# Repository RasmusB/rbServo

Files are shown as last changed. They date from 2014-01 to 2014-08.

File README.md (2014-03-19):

# rbServo Readme

### What is it?
All the hardware and software that is needed to build a CAN-BUS servo controller. It is meant to be used for RC servos.

### What does it contain?

- `3D` - hardware components

- `HW` - all the hardware design files are in this folder

- `SW` - The software for the servo.
 - `rbServoFirmware` - Servo controller firmware

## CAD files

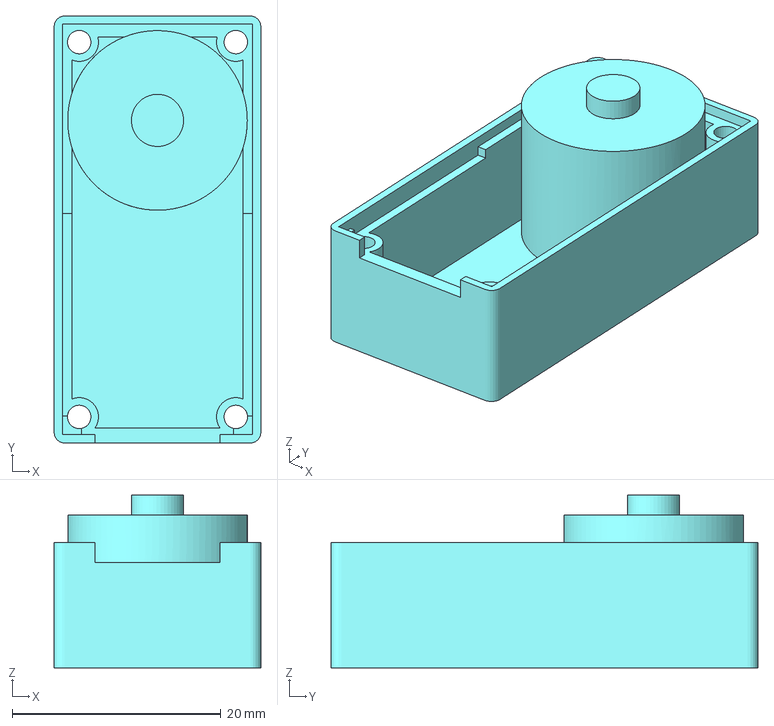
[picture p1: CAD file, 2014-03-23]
3D/rbServo-Assy.fcstd
19.8 x 40.9 x 16.5 mm

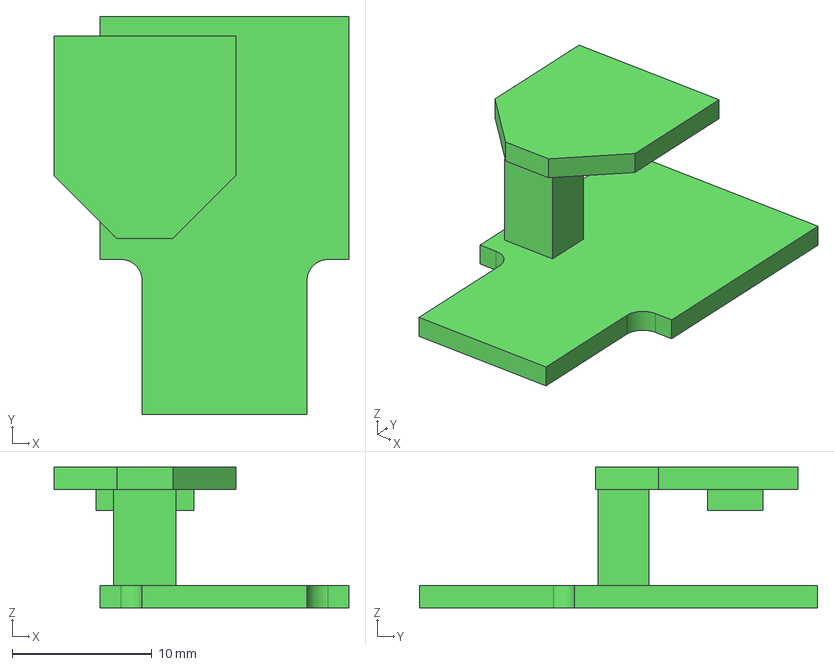
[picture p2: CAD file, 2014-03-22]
3D/rbServo-PCB.fcstd
21.1 x 28.5 x 10.1 mm

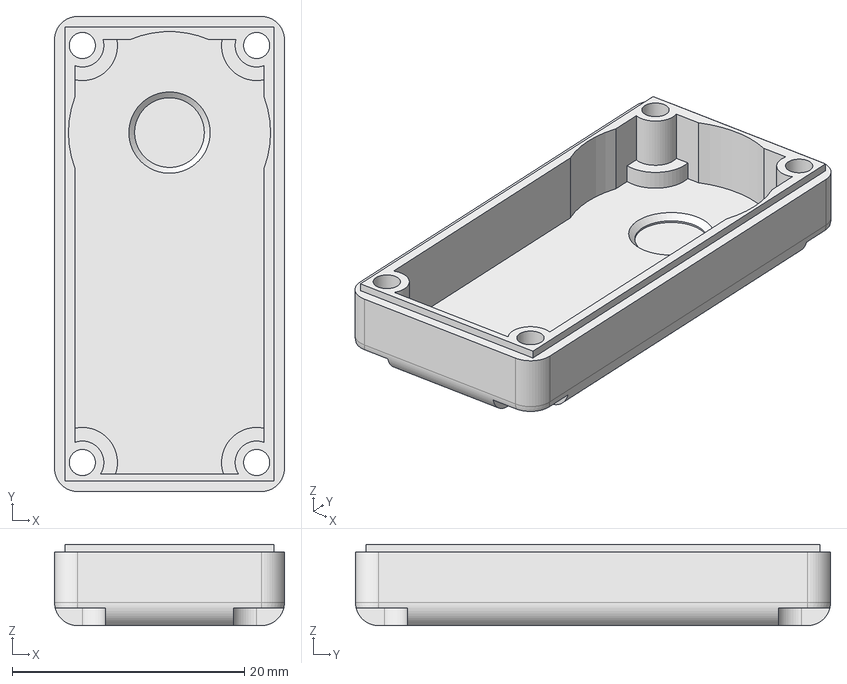
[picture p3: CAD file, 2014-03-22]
3D/MG995 Servo Lid.fcstd
19.8 x 40.9 x 7.00 mm

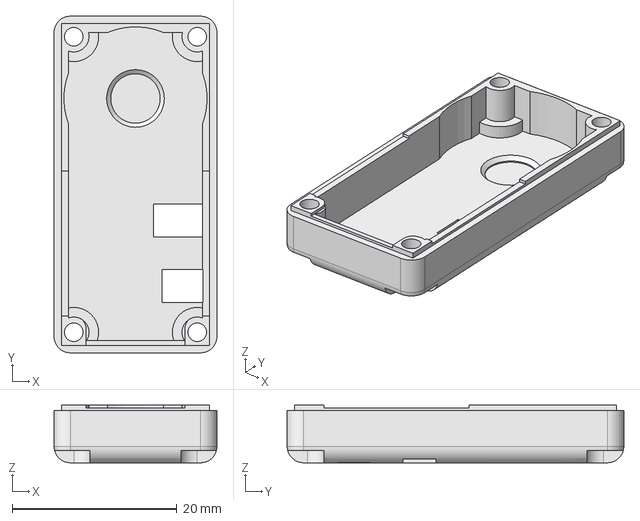
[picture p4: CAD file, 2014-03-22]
3D/rbServo-Lid.fcstd
19.8 x 40.9 x 7.00 mm

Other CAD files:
3D/rbServo-Body.fcstd
3D/MG995 Servo Body.fcstd

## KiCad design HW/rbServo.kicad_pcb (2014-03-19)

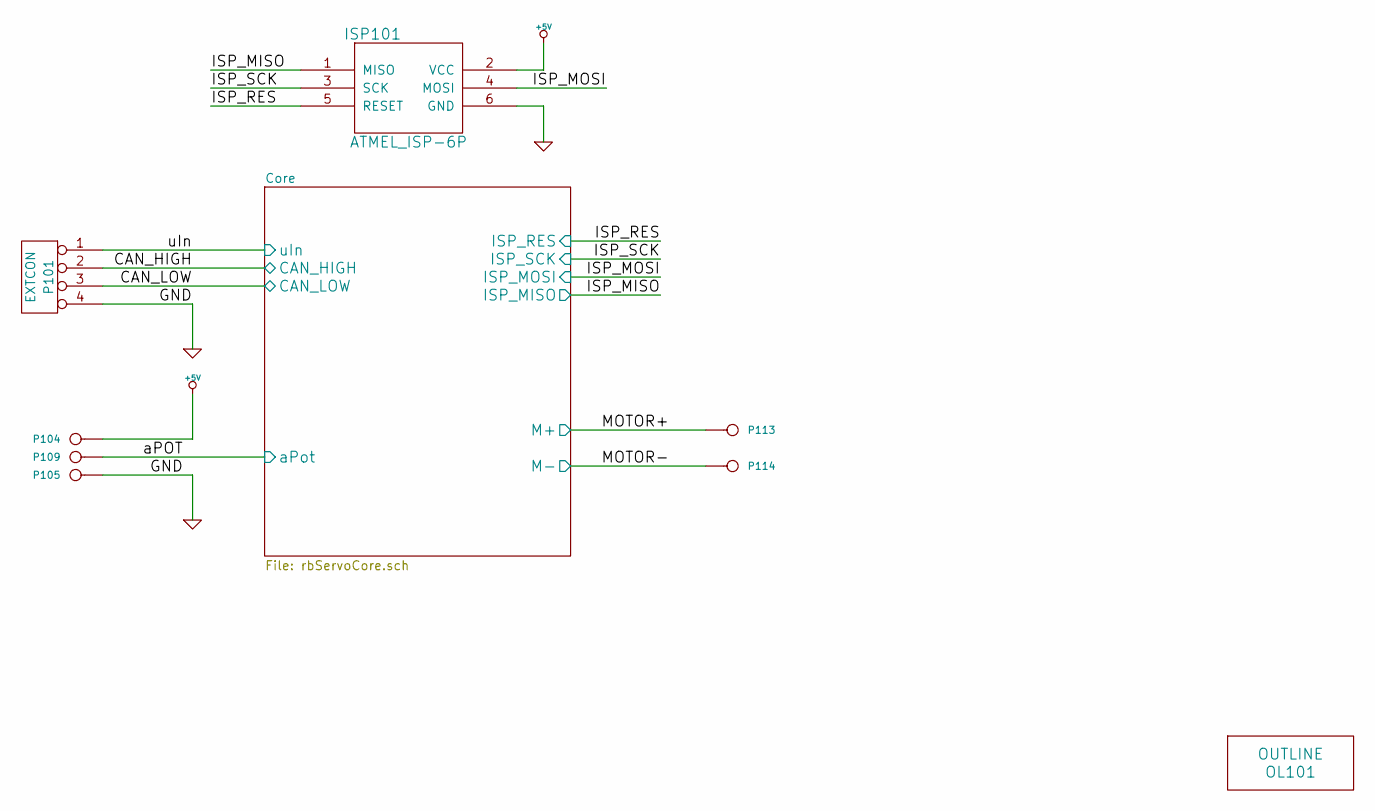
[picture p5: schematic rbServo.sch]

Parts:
ISP101: ATMEL_ISP-6P
OL101: OUTLINE
P101: EXTCON
P104: 5V
P105: GND
P109: Pot
P113: M+
P114: M-

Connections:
+5V: ISP101.2 (VCC), P104.1; also elsewhere on the board
/Core/CAN_HIGH: P101.2; also elsewhere on the board
/Core/CAN_LOW: P101.3; also elsewhere on the board
/Core/ISP_MISO: ISP101.1 (MISO); also elsewhere on the board
/Core/ISP_MOSI: ISP101.4 (MOSI); also elsewhere on the board
/Core/ISP_RES: ISP101.5 (RESET); also elsewhere on the board
/Core/ISP_SCK: ISP101.3 (SCK); also elsewhere on the board
/Core/M+: P113.1; also elsewhere on the board
/Core/M-: P114.1; also elsewhere on the board
/Core/aPot: P109.1; also elsewhere on the board
/Core/uIn: P101.1; also elsewhere on the board
GND: ISP101.6 (GND), P101.4, P105.1; also elsewhere on the board

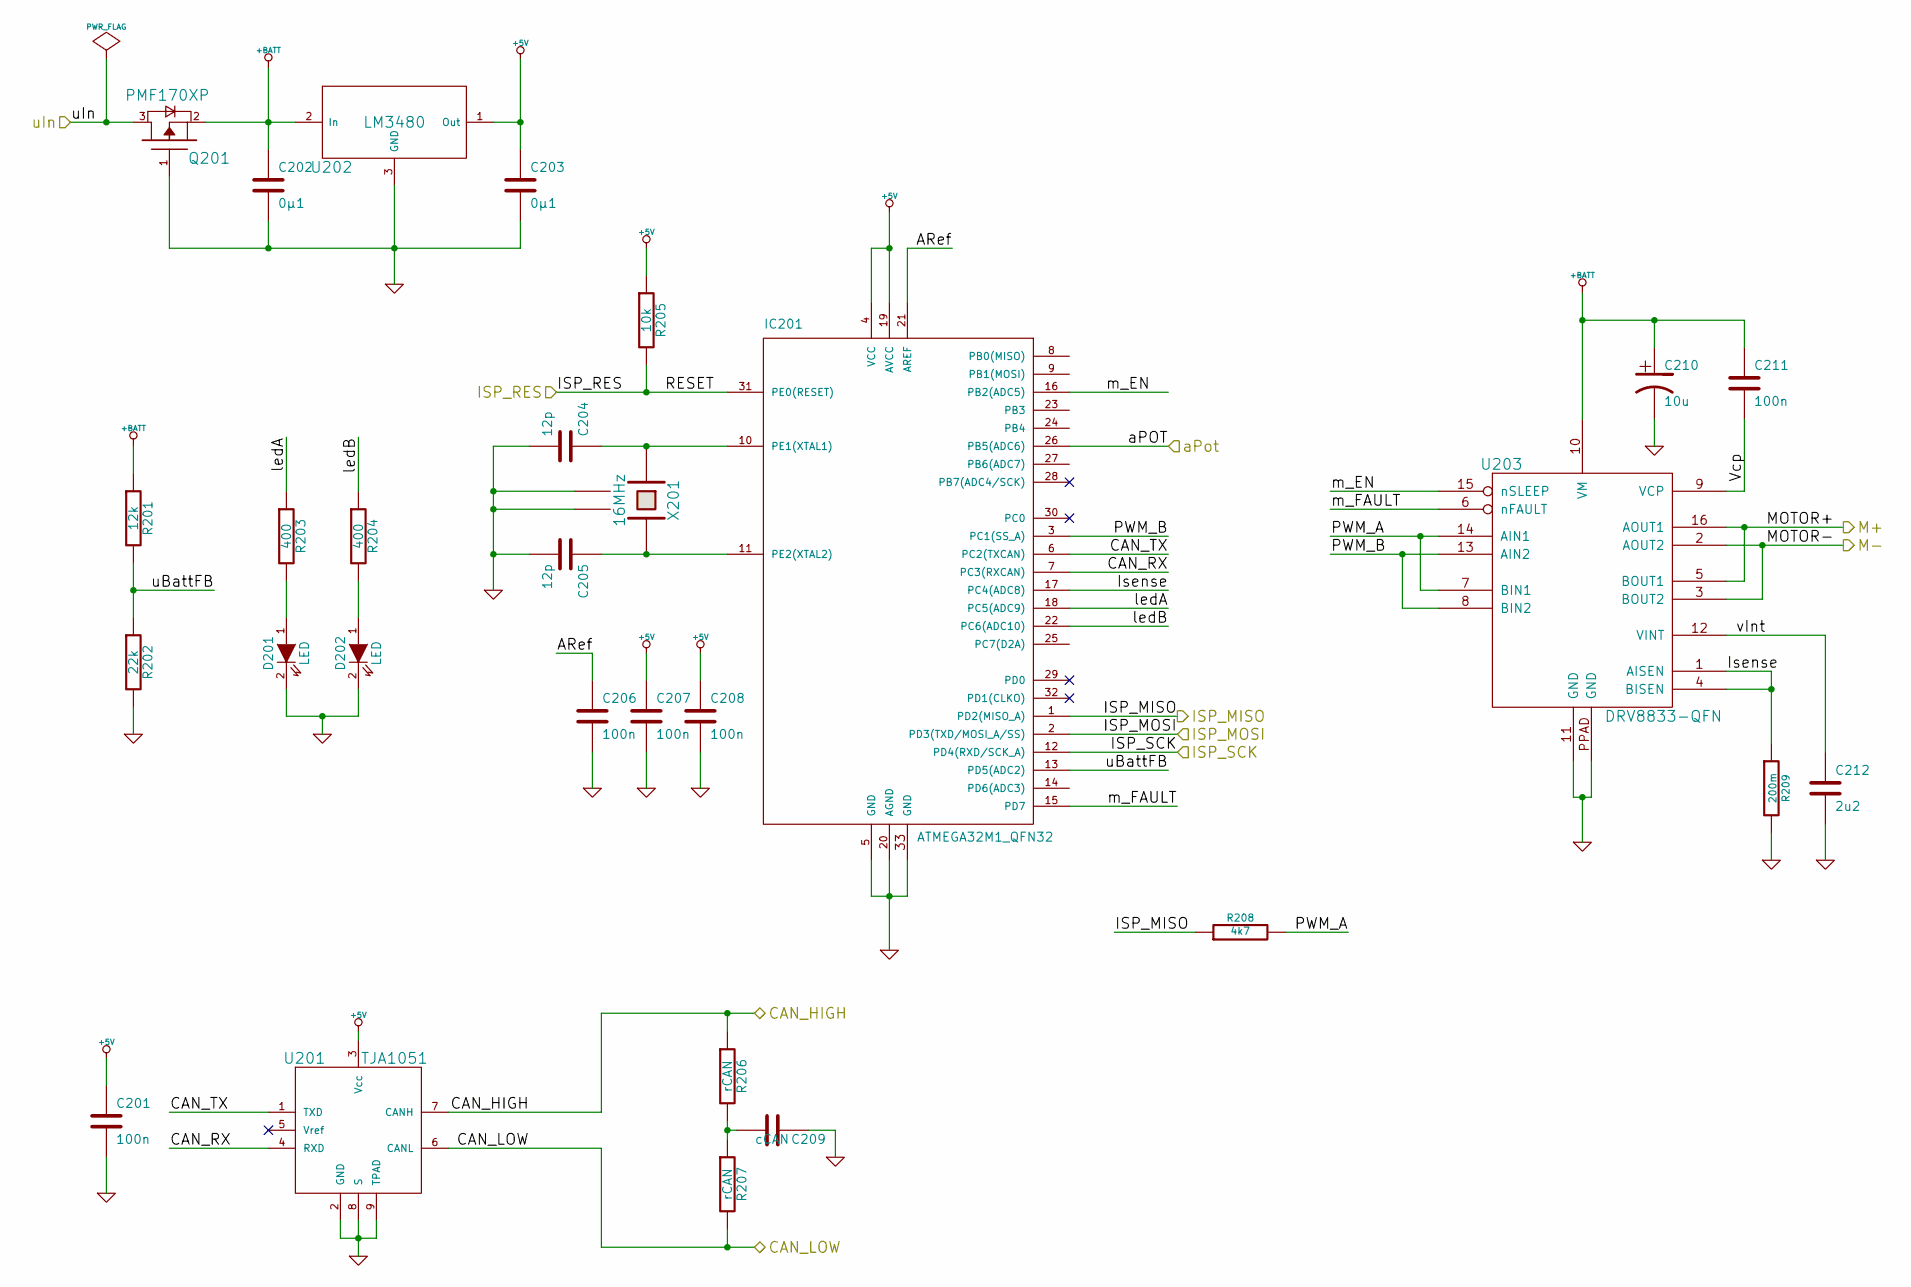
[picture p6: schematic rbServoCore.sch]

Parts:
C201, C206, C207, C208, C211: 100n
C202, C203: 0µ1
C204, C205: 12p
C209: cCAN
C210: 10u
C212: 2u2
D201, D202: LED
IC201: ATMEGA32M1_QFN32; MLF32
Q201: PMF170XP
R201: 12k
R202: 22k
R203, R204: 400
R205: 10k
R206, R207: rCAN
R208: 4k7
R209: 200m
U201: TJA1051
U202: LM3480; Mouser 926-LM3480IM35.0NOPB
U203: DRV8833-QFN
X201: 16MHz

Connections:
+5V: C201.1, C203.1, C207.1, C208.1, IC201.4 (VCC), IC201.19 (AVCC), R205.1, U201.3 (Vcc), U202.1 (Out); also elsewhere on the board
+BATT: C202.1, C210.1, C211.1, Q201.2 (S), R201.1, U202.2 (In), U203.10 (VM)
/Core/ARef: C206.1, IC201.21 (AREF)
/Core/CAN_HIGH: R206.1, U201.7 (CANH); also elsewhere on the board
/Core/CAN_LOW: R207.2, U201.6 (CANL); also elsewhere on the board
/Core/CAN_RX: IC201.7 (PC3(RXCAN)), U201.4 (RXD)
/Core/CAN_TX: IC201.6 (PC2(TXCAN)), U201.1 (TXD)
/Core/ISP_MISO: IC201.1 (PD2(MISO_A)), R208.1; also elsewhere on the board
/Core/ISP_MOSI: IC201.2 (PD3(TXD/MOSI_A/SS)); also elsewhere on the board
/Core/ISP_RES: IC201.31 (PE0(RESET)), R205.2; also elsewhere on the board
/Core/ISP_SCK: IC201.12 (PD4(RXD/SCK_A)); also elsewhere on the board
/Core/Isense: IC201.17 (PC4(ADC8)), R209.1, U203.1 (AISEN), U203.4 (BISEN)
/Core/M+: U203.5 (BOUT1), U203.16 (AOUT1); also elsewhere on the board
/Core/M-: U203.2 (AOUT2), U203.3 (BOUT2); also elsewhere on the board
/Core/PWM_A: R208.2, U203.7 (BIN1), U203.14 (AIN1)
/Core/PWM_B: IC201.3 (PC1(SS_A)), U203.8 (BIN2), U203.13 (AIN2)
/Core/Vcp: C211.2, U203.9 (VCP)
/Core/aPot: IC201.26 (PB5(ADC6)); also elsewhere on the board
/Core/ledA: IC201.18 (PC5(ADC9)), R203.1
/Core/ledB: IC201.22 (PC6(ADC10)), R204.1
/Core/m_EN: IC201.16 (PB2(ADC5)), U203.15 (nSLEEP)
/Core/m_FAULT: IC201.15 (PD7), U203.6 (nFAULT)
/Core/uBattFB: IC201.13 (PD5(ADC2)), R201.2, R202.1
/Core/uIn: Q201.3 (D); also elsewhere on the board
/Core/vInt: C212.1, U203.12 (VINT)
GND: C201.2, C202.2, C203.2, C204.2, C205.2, C206.2, C207.2, C208.2, C209.1, C210.2, C212.2, D201.2 (K), D202.2 (K), IC201.5 (GND), IC201.20 (AGND), IC201.33 (GND), Q201.1 (G), R202.2, R209.2, U201.2 (GND), U201.8 (S), U201.9 (TPAD), U202.3 (GND), U203.11 (GND), U203.PPAD (GND), X201.2 (GND), X201.4 (GND); also elsewhere on the board
unnamed: C204.1, IC201.10 (PE1(XTAL1)), X201.1
unnamed: C205.1, IC201.11 (PE2(XTAL2)), X201.3
unnamed: C209.2, R206.2, R207.1
unnamed: D201.1 (A), R203.2
unnamed: D202.1 (A), R204.2

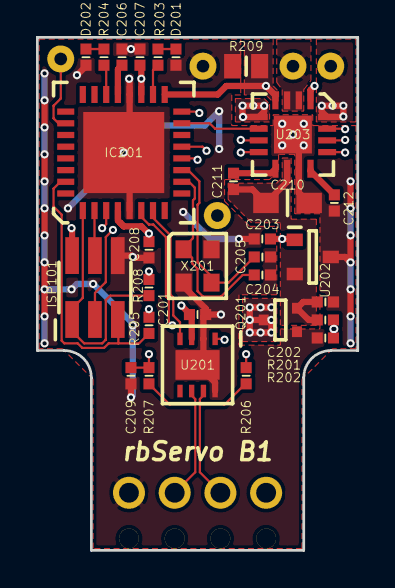
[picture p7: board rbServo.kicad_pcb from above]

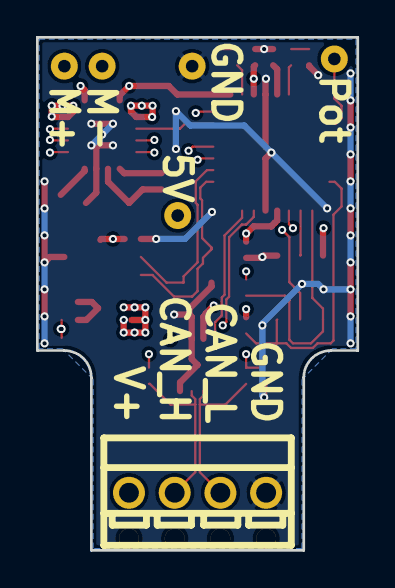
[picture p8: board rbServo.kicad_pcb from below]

Board: 4 copper layers, 17.8 x 28.5 mm, 37 parts (6 on the bottom side), 31 nets.

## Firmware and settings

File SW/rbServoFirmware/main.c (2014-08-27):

/*
The MIT License (MIT)

Copyright (c) 2014 Rasmus Backman

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
THE SOFTWARE IS PROVIDED "AS IS", WITHOUT WARRANTY OF ANY KIND, EXPRESS OR
IMPLIED, INCLUDING BUT NOT LIMITED TO THE WARRANTIES OF MERCHANTABILITY,
FITNESS FOR A PARTICULAR PURPOSE AND NONINFRINGEMENT. IN NO EVENT SHALL THE
AUTHORS OR COPYRIGHT HOLDERS BE LIABLE FOR ANY CLAIM, DAMAGES OR OTHER
LIABILITY, WHETHER IN AN ACTION OF CONTRACT, TORT OR OTHERWISE, ARISING FROM,
OUT OF OR IN CONNECTION WITH THE SOFTWARE OR THE USE OR OTHER DEALINGS IN THE
SOFTWARE.
*/

#include <avr/io.h>
#include <avr/interrupt.h>
#include <stdlib.h>
#include <stdbool.h>

#include "adc.h"
#include "board.h"
#include "canbus.h"
#include "eepromConfig.h"
#include "motor.h"
//#include "pid.h"
#include "sensors.h"
#include "timer.h"

#define MOTOR_SPEED 0x1EFF

void init(void) __attribute__((constructor));

extern uint16_t sensorPotGetRaw();

uint8_t mirrorMCUSR __attribute__ ((section (".noinit")));

int main () {

	uint16_t i;

	mirrorMCUSR = MCUSR;

	// TODO: Check for new CAN data. Update behavior accordingly.

	// TODO: Check if enough time has elapsed. If so, update PID.
	// TODO: Update PWM output according to PID output

	// TODO: Update remote CAN frame data
		/*	disable "data valid" flag
		 *	write new data to buffer
		 *	set "data valid" flag
		 */

	grnLEDpwm( 0xFF );

//	motorSetSpeed ( MOTOR_SPEED );


	while (1) {

		int16_t tempPot = sensorPotGetValue();

		if (run10HzLoop) {
			run10HzLoop = 0;

			redLEDon();

//			if ( tempPot > 150 ) {
//				motorSetSpeed ( -MOTOR_SPEED );
//			} else if ( tempPot < -150 ) {
//				motorSetSpeed ( MOTOR_SPEED );
//			}

			canbusTxBuffer[1] = (int8_t) (tempPot >> 8);
			canbusTxBuffer[0] = (uint8_t) (tempPot & 0xFF);

			canbusTXsetup(010, 2, 1);

			redLEDoff();

		}





//		canbusRXsetup(0);
//
//		// Busy-Wait for a CAN message
//		while (CANSTMOB == 0);
//		CANSTMOB = 0x00;
//
//		rxID = (CANIDT1 << 3) + (CANIDT2 >> 5);
//		rxDLC = CANCDMOB & 0x0F;
//
//		for (i=0; i < rxDLC; i++) {
//			canbusRxDataBuffer[i] = CANMSG;
//		}
//
//		if (rxID == 0x123 && rxDLC == 2) {
//			pwmSetDutyCycle((canbusRxDataBuffer[0] << 8) + canbusRxDataBuffer[1]);
//		}

		//canbusTXsetup(rxID, rxDLC, 0); 	// This just echos the last received message

	}



	return 0;
}

void init() {
	// Read all node configuration data
	eepromReadConfiguration();

	// Initialize board IO
	boardInit();

	// Initialize AD converter
	adcInit();

	// Initialize PWM generation
	motorInit();

	// Initialize timer-based interrupts
	timerInit();

	// Initialize CAN bus
	canbusInit();

	// TODO: Initialize PID with EEPROM values
	// TODO: PID setpoint = current position

	// Enable Global Interrupts
	sei();
}

ISR(BADISR_vect)
{
    // This should not ever happen!
	// If this function executes, an unhandled interrupt occured.

	while (1) {
		redLEDon();
		grnLEDon();
	}
}

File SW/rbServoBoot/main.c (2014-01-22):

/*
 * main.c
 *
 *  Created on: Jan 22, 2014
 *      Author: rasmus
 */


// TODO: Create timer with mS resolution for PID loop

#include <avr/io.h>

#include "board.h"
#include "canbus.h"
#include "eepromConfig.h"

void init(void) __attribute__((constructor));

int main () {

	uint8_t i;
	uint8_t j;
	uint16_t rxID;
	uint8_t rxDLC;
	// TODO: Check for new CAN data. Update behavior accordingly.

	// TODO: Check if enough time has elapsed. If so, update PID.
	// TODO: Update PWM output according to PID output

	// TODO: Update remote CAN frame data
		/*	disable "data valid" flag
		 *	write new data to buffer
		 *	set "data valid" flag
		 */

	//redLEDpwm(0);
	while (1) {

		canbusRXsetup(0);

		// Busy-Wait for a CAN message
		while (CANSTMOB == 0);
		CANSTMOB = 0x00;

		rxID = (CANIDT1 << 3) + (CANIDT2 >> 5);
		rxDLC = CANCDMOB & 0x0F;

		//redLEDpwm(CANIDT1);

		for (i=0; i < rxDLC; i++) {
			canbusDataBuffer[i] = CANMSG;
		}

		// Send message
		canbusTXsetup(rxID, rxDLC, 0);
	}



	return 0;
}

void init() {
	boardInit();
	//eepromReadConfiguration();
	//adcInit();

	canbusInit();

	// TODO: Initialize PID with EEPROM values
		// TODO: PID setpoint = current position
	//redLEDoff();

	// First boot since reflash via bootloader
	/*
	if (BootStayIn) {
		BootStayIn = 0;
		eepromWriteConfiguration();
	}
	*/
	// Enable Global Interrupts
	SREG |= _BV(SREG_I);

	// TODO: Send CANBUS "Application Ready"
	// TODO: Wait for CANBUS "OK" response

}

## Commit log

2014-01-22 Initial commit, nothing useful yet
    [rbServoCore.sch, rbServoFinal.kicad_pcb, rbServoFinal.sch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]
2014-03-11 Work on all fronts. The software is taking shape now.
    [rbServoCore.sch, rbServoProto.kicad_pcb, rbServoProto.sch]
2014-03-12 .gitignore updated to ignore all KiCAD temporary "BAK" files
2014-03-12 Remove unneeded PWM for now
2014-03-12 Cleanup in the HW directory. - The "proto", "final" and "common" directories are joined to one single design, based on the latest prototype design. - Readme.md updated to reflect this change
    [rbServo.kicad_pcb, rbServo.sch, rbServoCore.sch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]
2014-03-13 Added simple software-based PWM for on board LED
2014-03-18 Trying new layout
    [rbServo.kicad_pcb, rbServo.sch]
2014-03-18 Started work on new servo lid for Tower Pro MG995 servo
    [Servo Lid.fcstd]
2014-03-19 -Swapped CAN_H and CAN_L -Changed a few labels - All new layout that should fit i a servo
    [rbServo.kicad_pcb, rbServo.sch, rbServoCore.sch]
2014-03-22 New version of the servo lid. A debugger port hole needs to be added for a debugger compatible version.
    [Servo Lid.fcstd]
2014-03-22 Work in progress on mechanical fit
    [MG995 Servo Body.fcstd, Servo Lid.fcstd, rbServo-RevB1-Assy.fcstd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]
2014-03-22 Servo lid model renamed for clarity
    [MG995 Servo Lid.fcstd, Servo Lid.fcstd]
2014-03-22 Model structure tweaks
    [MG995 Servo Body.fcstd, rbServo-RevB1-Assy.fcstd, rbServo-RevB1-PCB.fcstd]
2014-03-22 Another revision of the servo body to document the modifications needed to fit the B1 PCB.
    [rbServo-RevB1-Body.fcstd]
2014-03-23 Reshuffled file names again.
    No use having the filenames contain the version name when
    I'm using a version control system... doh!
    [rbServo-Assy.fcstd, rbServo-Body.fcstd, rbServo-Lid.fcstd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]
2014-03-25 Added license and refactored
    - Added license information to source code (resolves issue #6)
    - Broke out ADC routines to own file
    - Broke out Timer interrupt handling to own file
    - Added EEPROM node configuration paramters
    [adc.c, board.c, main.c]
2014-03-26 Minor pin config additions
